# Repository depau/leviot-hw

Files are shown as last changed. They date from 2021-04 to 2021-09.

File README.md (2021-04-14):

# LevIoT - Air Purifier replacement controller

This is a replacement PCB based on ESP32 for the Levoit "True HEPA Air Purifier" Core 300, (Amazon model number: 817915027059).

It has currently not been tested yet, I just ordered it from a PCB manufacturer.

I spent around 30€ for 5 PCBs with most components pre-soldered by the PCB manufacturer, + around 13€ on AliExpress for the
push buttons, shift registers and PH connectors.

Touchpad springs and LEDs are going to be recovered from the original PCB.

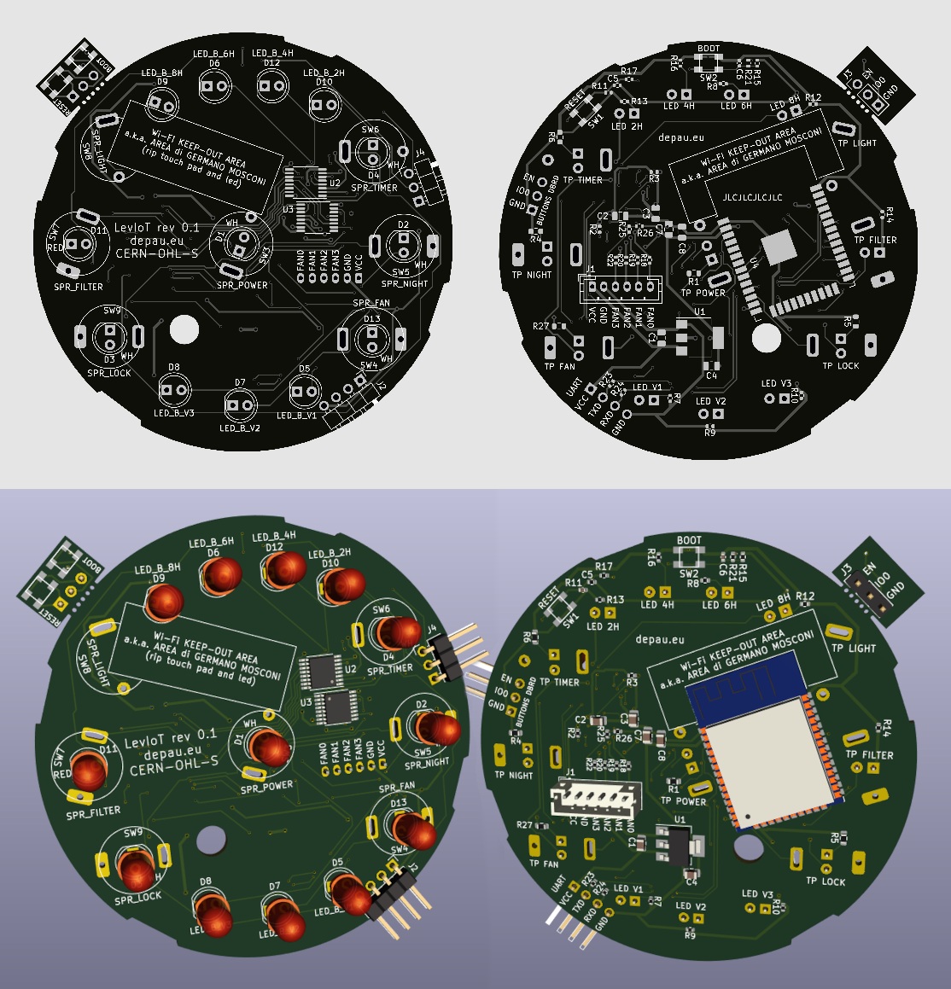
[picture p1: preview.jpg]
preview


## Taking the original board out

The top cover comes off by inserting a spudger tool between the top white and gray plastic parts.

The PCB is attached to the top plastic lid with some clips, and connected to the motor via a 6-pin JST-PH connector.

## Control board protocol

Pinout:

| Pin # | Function |
| --- | --- |
| 1 (red) | VCC |
| 2 | GND |
| 3 | Speed 3 |
| 4 | Speed 2 |
| 5 | Speed 1 |
| 6 | Night mode |

The control board simply pulls one of the pins from 3 to 6 high with the other ones low to set the speed, with all low being "off".

The motor side seems to accept pretty much any voltage > 1V as long as the current is at least ~20 mA, though when using the original
board I measure 4V across the pin and ground - current should be around 80 mA.

You can test it by placing a 100 ohm resistor between 5V and one of the speed pins.

### Important safety notice

I'm not an electrical motor expert but I know that fans need to be started at the maximum speed from the off state in order to
prevent motor strain, overheating and fire hazards.

See this video about it by Technology Connections: https://www.youtube.com/watch?v=hQ3GW7lVBWY

A custom board firmware must kickstart the fan at maximum speed for ~1 sec after power on, then set it back to whatever speed
is desired.

The original board does this automatically.

## License

CERN Open Hardware License, strictly reciprocal.

## Disclaimer

I will not take any responsibility for broken air filters caused by modding or installing this custom PCB. You take your own
responsibility.

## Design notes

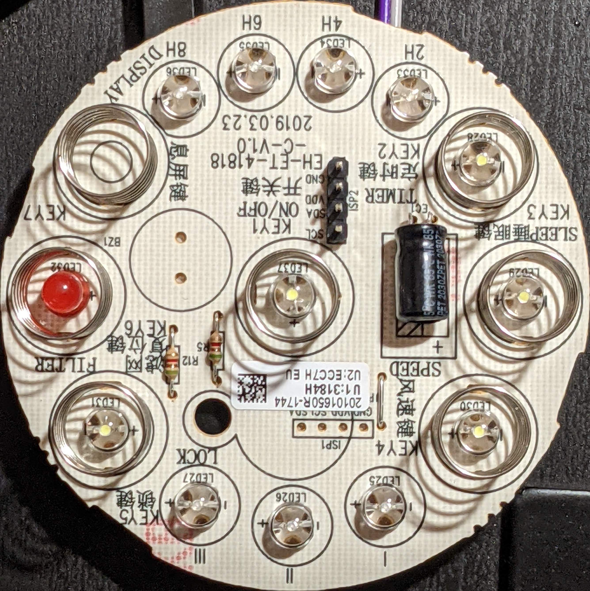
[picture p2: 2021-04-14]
front.jpg

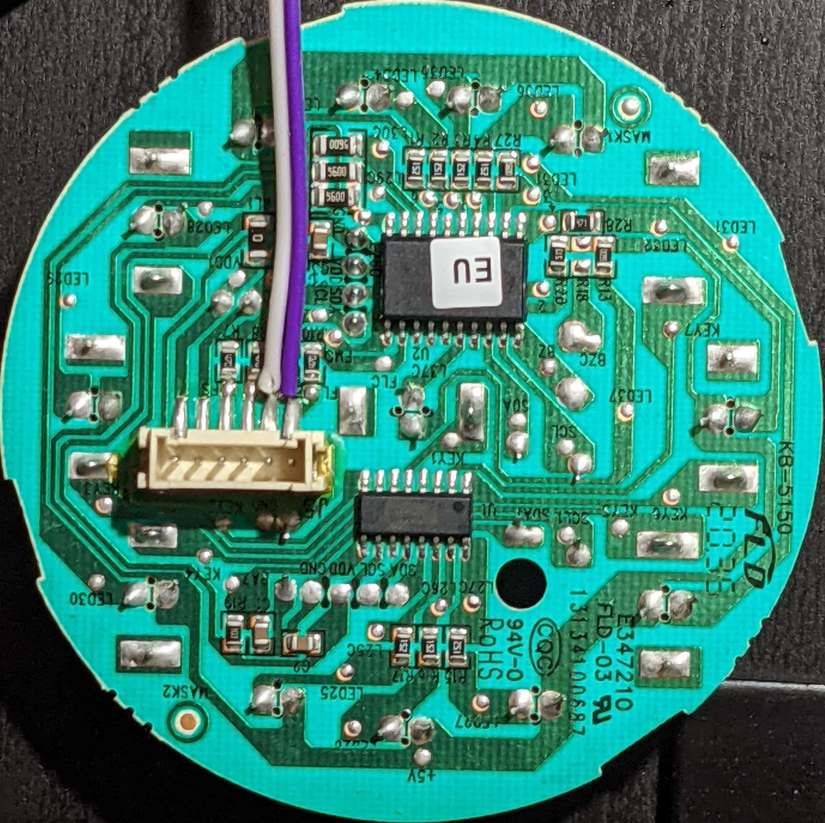
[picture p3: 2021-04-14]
back.jpg

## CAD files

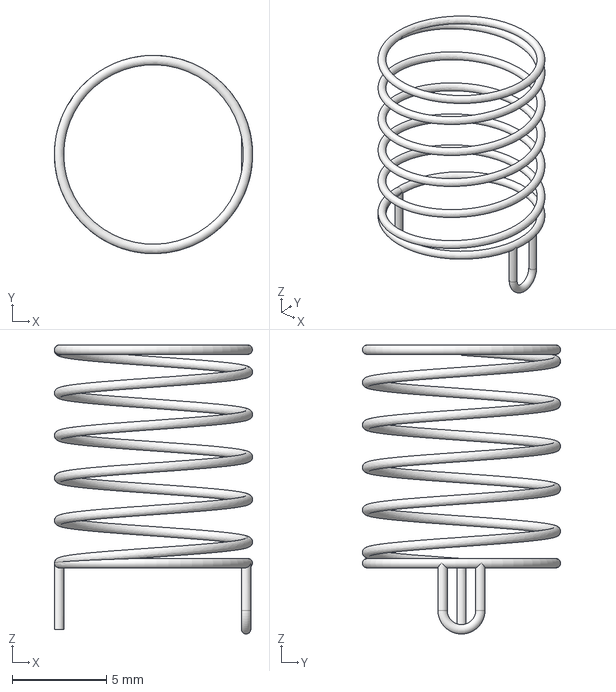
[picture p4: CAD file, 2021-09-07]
spring-3d-model/spring-3d-model.step
10.5 x 10.5 x 15.3 mm

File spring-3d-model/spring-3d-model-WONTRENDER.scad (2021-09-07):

wire_thickn = 0.5;
height = 13;
diam = 10.9;
windings = 5;
pin_len = 3.5;
slot_w = 2;

fn = 50;

/**
* An edge (or line) between 2 nodes
*/
module line(start, end, d, fn=4) {
  hull() {
    node(start,d, fn);
    node(end,d, fn);
  }      
}

/**
* A single node which is connected by edges
*/

module node(pos, d, fn=4) {
  if (pos[0]!=undef && pos[1] != undef && pos[2] != undef){ 
    translate(pos) sphere(d=d, $fn = fn);    
  }
}

module spring(d, dBottom=6, dTop=6, windings=2, height=10, steps=10, wireDiameter=1,fn=10) {
    // we use either d or dBottom&dTop
    r0 = d != undef ? d/2 : dBottom/2;
    r1 = d != undef ?d/2 : dTop/2;
    
    rx = (r0-r1) / (360.0*windings);    
    heightPerDegree = height/windings/360;
    
    for ( angle = [steps : steps : 360*windings] ){
        r = r0 - (angle * rx); 
        x0=r*cos(angle-steps);
        y0=r*sin(angle-steps);
        z0=(angle-steps)*heightPerDegree;
        x=r*cos(angle);
        y=r*sin(angle);
        z=angle*heightPerDegree;

        line([x0,y0,z0],[x,y,z],d=wireDiameter,fn=fn);        
    }
}

/**
* 3D Spring with identical diameter at top and bottom. The top and boton might
* start with a flat circle
*/
module spring3D(d=5,windings=3,height=10,flatStart=true,flatEnd=true, wireDiameter=1,  fn=4) {  
    spring(d=d, windings=windings,height=height, wireDiameter=wireDiameter, fn=fn);
    
    if (flatStart)
        spring(dBottom=d,dTop=d,windings=1,height=0, wireDiameter=wireDiameter, fn=fn);
    if (flatEnd)
        translate([0,0,height]) spring(dBottom=d,dTop=d, windings=1,height=0, wireDiameter=wireDiameter, fn=fn);
}

union() {
  spring3D(diam, windings=windings, height=height, wireDiameter=wire_thickn, fn=fn);
  
  translate([-diam/2, 0, -pin_len - wire_thickn/2])
  cylinder(d=wire_thickn, h=pin_len+(wire_thickn/2), $fn=fn);
  
  translate([diam/2 , 0, -pin_len+slot_w-wire_thickn]) {
    rotate([90, 0, 90])
    rotate_extrude(angle=180, convexity=10, $fn=fn)
    translate([-slot_w/2 + wire_thickn, 0])
    circle(d=wire_thickn, $fn=fn);
    
    translate([0, -slot_w/2 + wire_thickn])
    cylinder(d=wire_thickn, h=pin_len-slot_w/2 - wire_thickn, $fn=fn);
    
    translate([0, slot_w/2 - wire_thickn])
    cylinder(d=wire_thickn, h=pin_len-slot_w/2 - wire_thickn, $fn=fn);
  }
}

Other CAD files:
spring-3d-model/spring-3d-model1.step
spring-3d-model/spring-3d-model.f3d
spring-3d-model/spring-3d-model1.f3d

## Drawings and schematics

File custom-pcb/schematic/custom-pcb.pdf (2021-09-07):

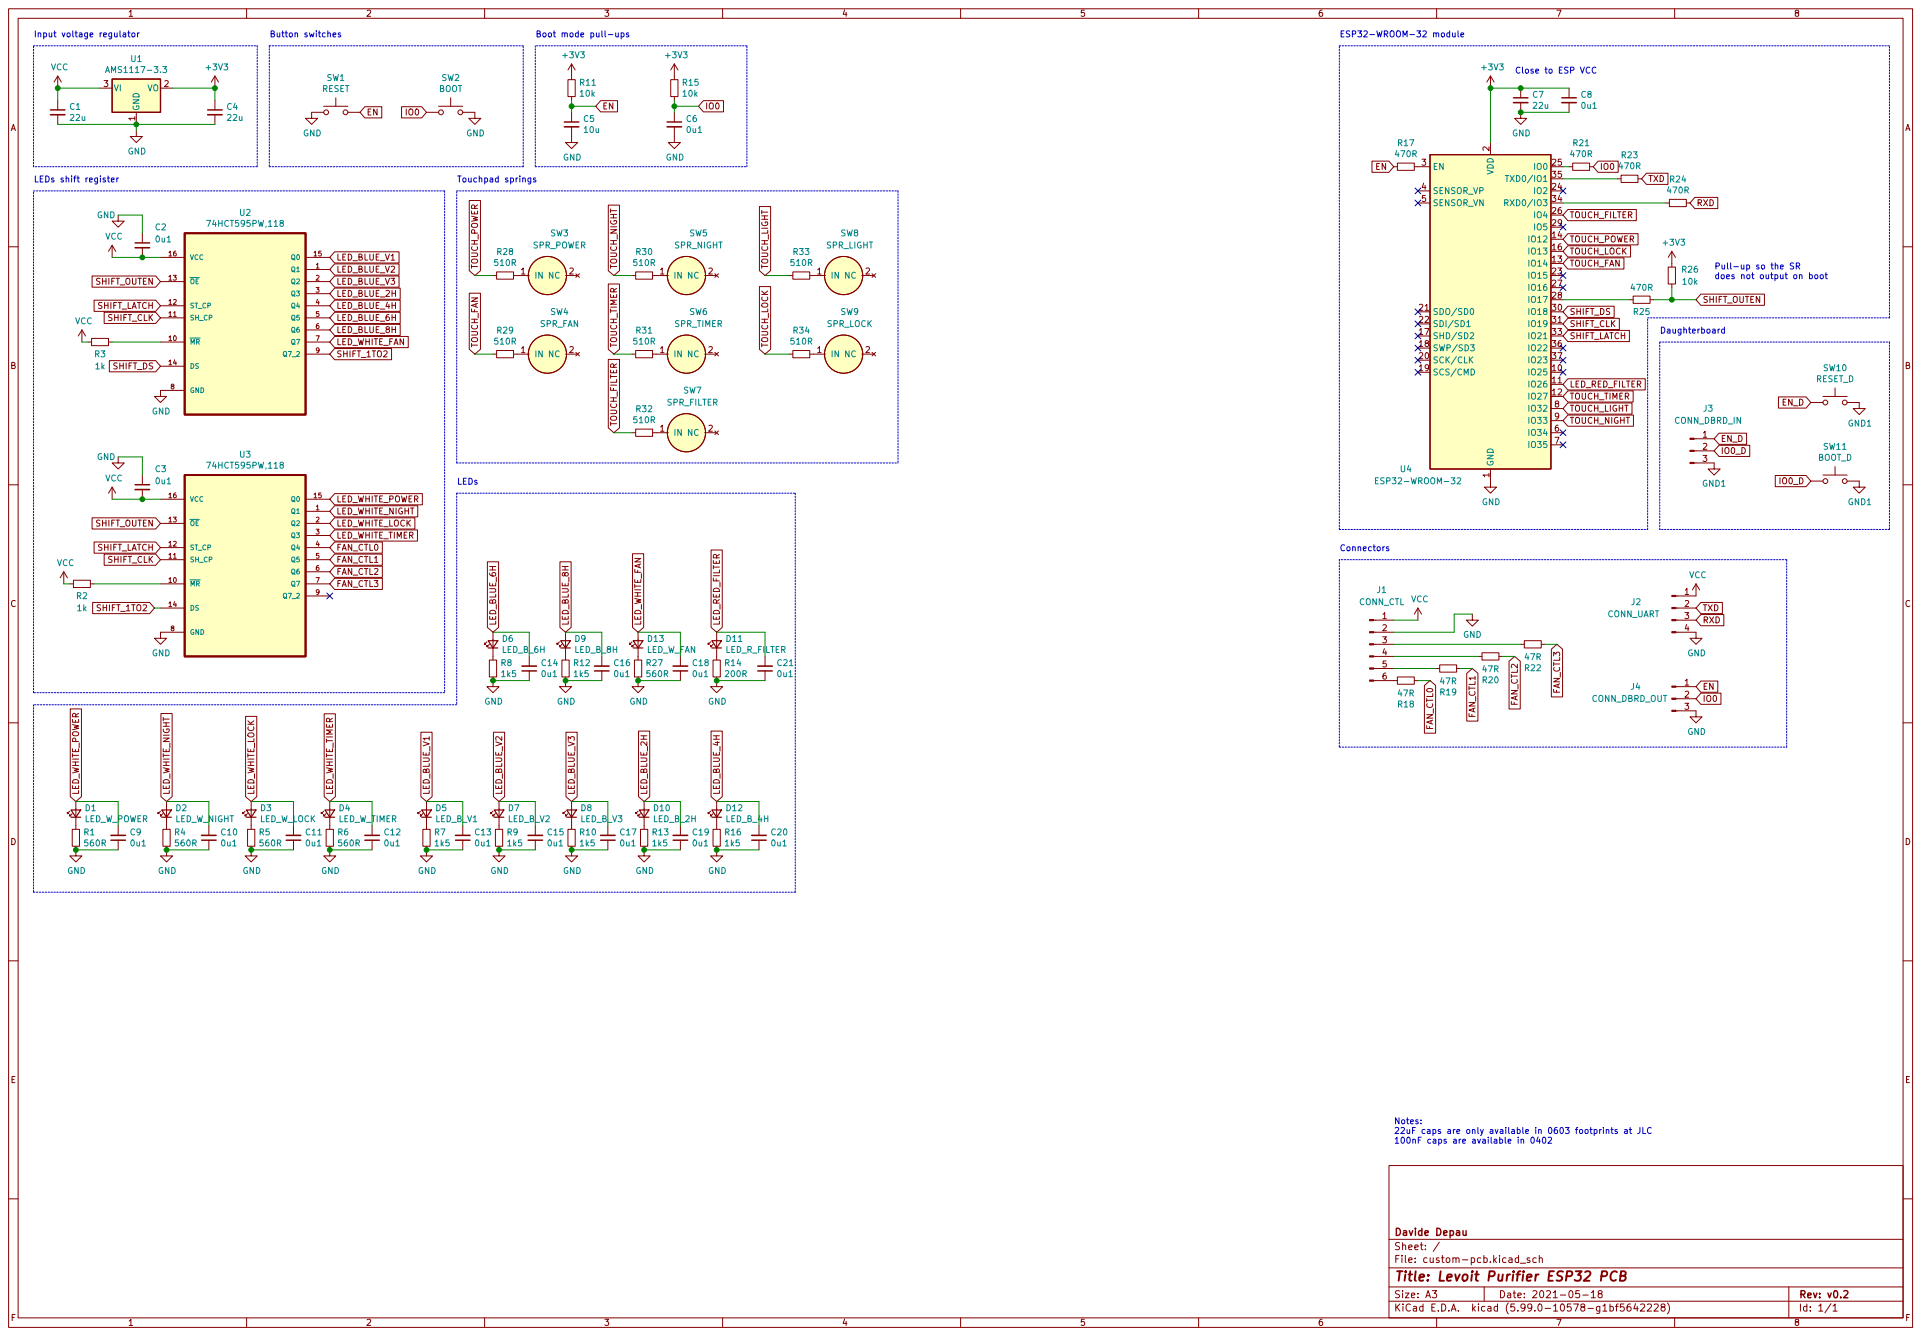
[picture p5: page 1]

Button switches LEDs shift register

2 SCK/CLK 20 SDO/SD0 21 SDI/SD1 22

Pull-up so the SR
does not output on boot

Notes: 22uF caps are only available in 0603 footprints at JLC

100nF caps are available in 0402

File: custom-pcb.kicad_sch Sheet: / Davide Depau

Id: 1/1 Title: Levoit Purifier ESP32 PCB

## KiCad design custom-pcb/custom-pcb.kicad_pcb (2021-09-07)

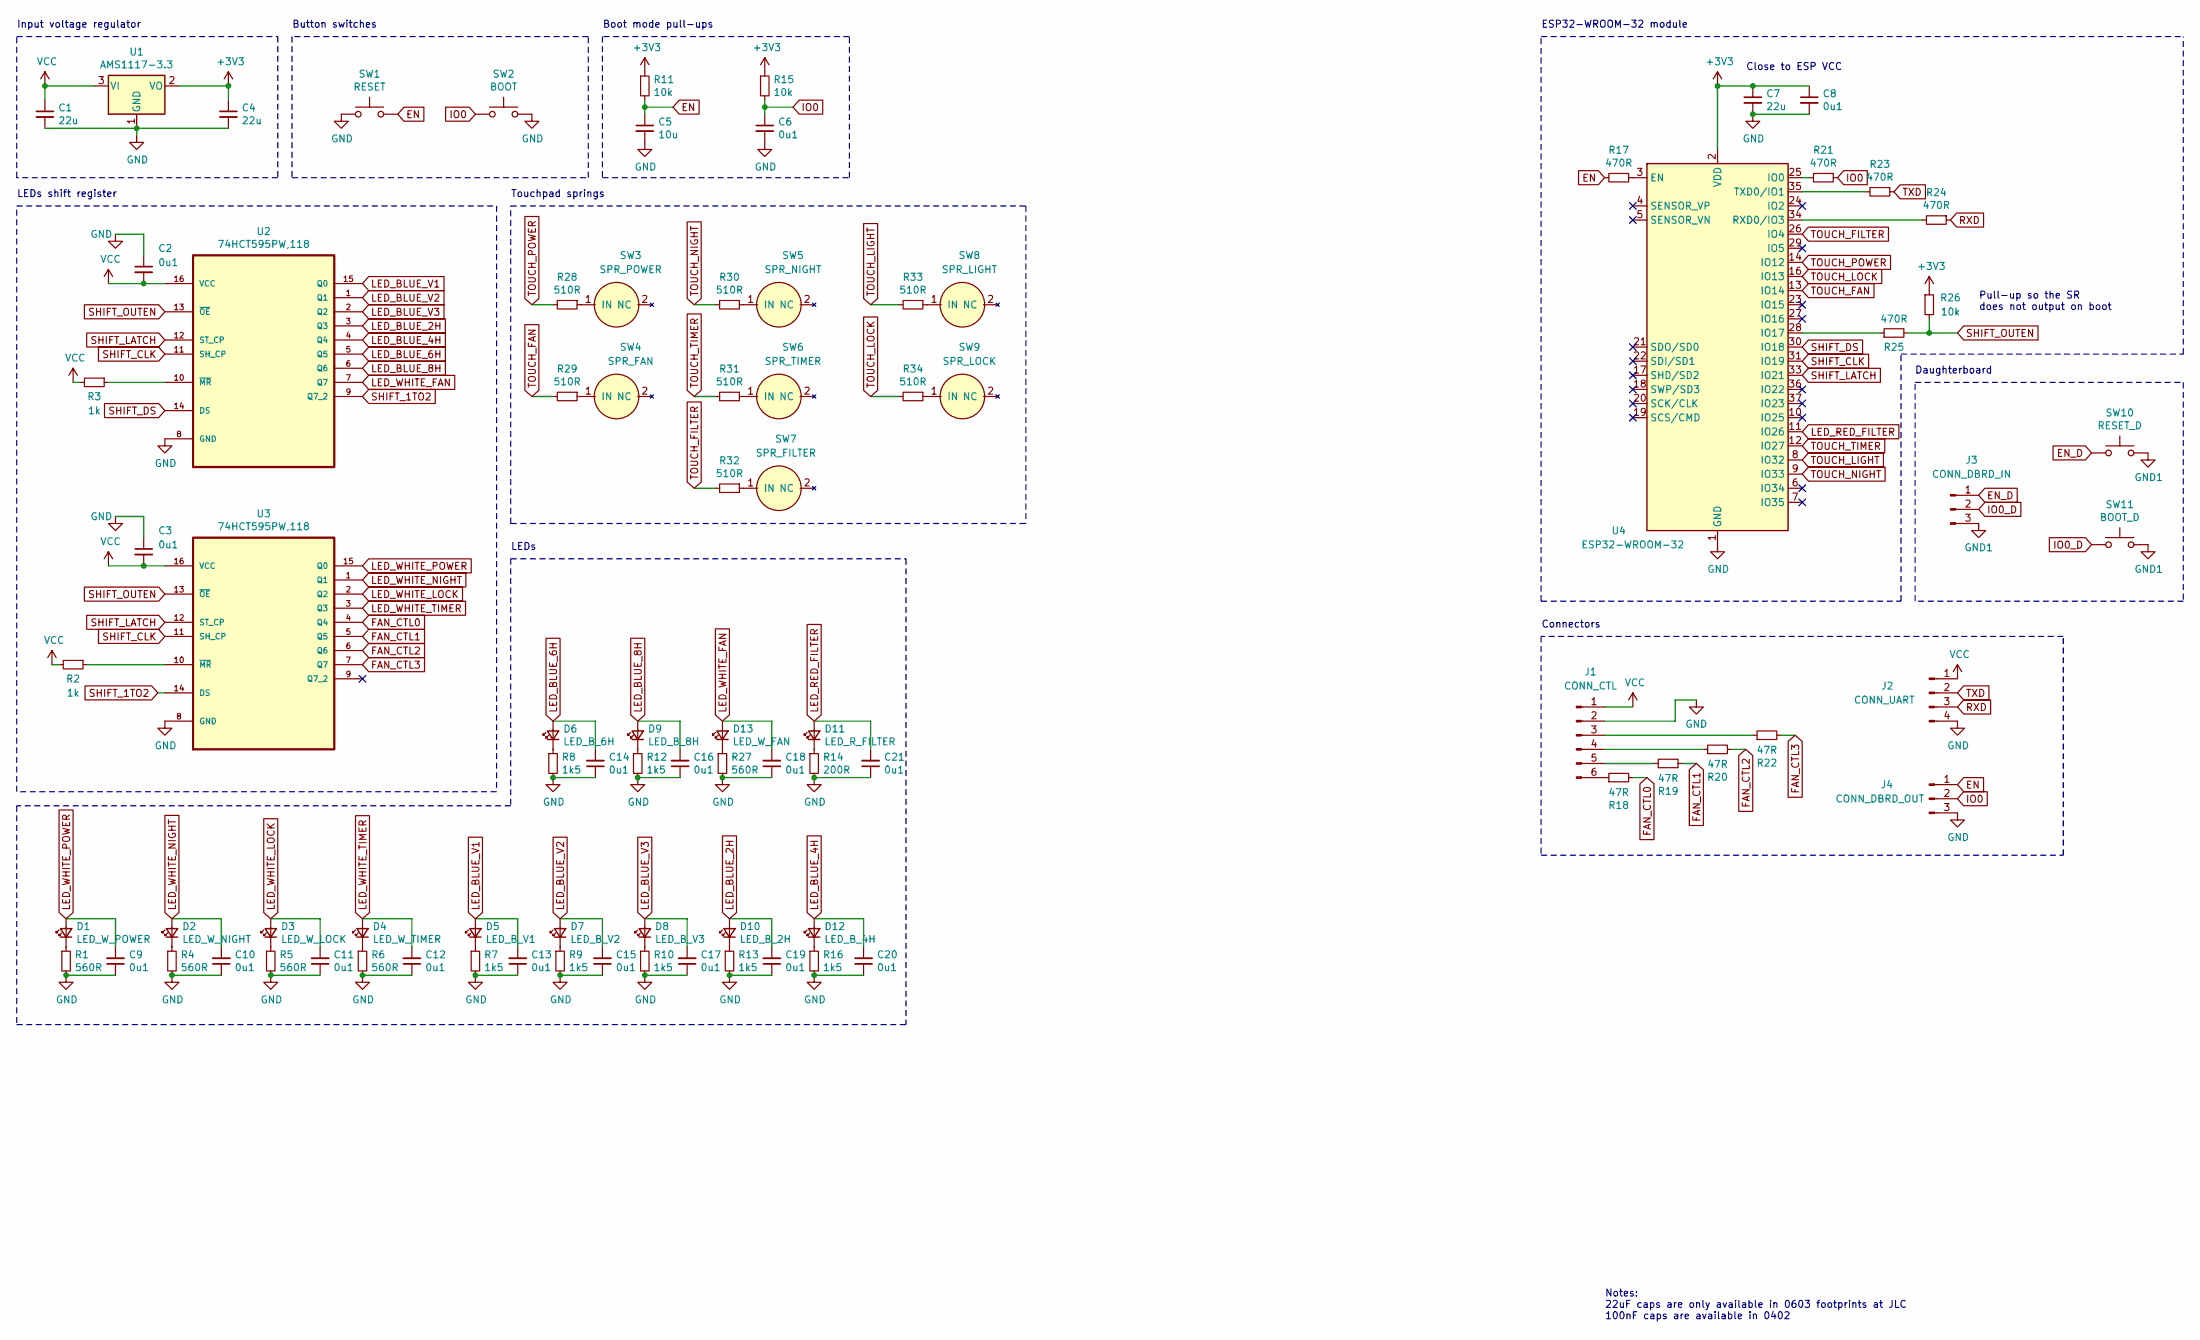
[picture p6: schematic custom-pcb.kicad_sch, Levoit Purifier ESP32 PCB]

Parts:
C1, C4, C7: 22u; C_0805_2012Metric; LCSC Part C45783
C2, C3, C8: 0u1; C_0805_2012Metric; LCSC Part C49678
C5: 10u; C_0402_1005Metric; LCSC Part C15525
C6: 0u1; C_0402_1005Metric; LCSC Part C1525
C9, C10, C11, C12, C13, C14, C15, C16, C17, C18, C19, C20, C21: 0u1; C_0402_1005Metric
D1: LED_W_POWER; LED_D5.0mm-centered; JLCPCB BOM 0
D2: LED_W_NIGHT; LED_D5.0mm-centered; JLCPCB BOM 0
D3: LED_W_LOCK; LED_D5.0mm-centered; JLCPCB BOM 0
D4: LED_W_TIMER; LED_D5.0mm-centered; JLCPCB BOM 0
D5: LED_B_V1; LED_0603_1608Metric_Pad1.05x0.95mm_HandSolder; JLCPCB BOM 0
D6: LED_B_6H; LED_0603_1608Metric_Pad1.05x0.95mm_HandSolder; JLCPCB BOM 0
D7: LED_B_V2; LED_0603_1608Metric_Pad1.05x0.95mm_HandSolder; JLCPCB BOM 0
D8: LED_B_V3; LED_0603_1608Metric_Pad1.05x0.95mm_HandSolder; JLCPCB BOM 0
D9: LED_B_8H; LED_0603_1608Metric_Pad1.05x0.95mm_HandSolder; JLCPCB BOM 0
D10: LED_B_2H; LED_0603_1608Metric_Pad1.05x0.95mm_HandSolder; JLCPCB BOM 0
D11: LED_R_FILTER; LED_D5.0mm-centered; JLCPCB BOM 0
D12: LED_B_4H; LED_0603_1608Metric_Pad1.05x0.95mm_HandSolder; JLCPCB BOM 0
D13: LED_W_FAN; LED_D5.0mm-centered; JLCPCB BOM 0
J1: CONN_CTL; JST_PH_B6B-PH-K_1x06_P2.00mm_Vertical; JLCPCB BOM 0
J2: CONN_UART; PinHeader_1x04_P2.54mm_Vertical; JLCPCB BOM 0
J3: CONN_DBRD_IN; PinHeader_1x03_P2.54mm_Vertical; JLCPCB BOM 0
J4: CONN_DBRD_OUT; PinHeader_1x03_P2.54mm_Vertical; JLCPCB BOM 0
R1, R4, R5, R6, R27: 560R; R_0603_1608Metric; LCSC Part C23204
R2, R3: 1k; R_0402_1005Metric; LCSC Part C11702
R7, R8, R9, R10, R12, R13, R16: 1k5; R_0402_1005Metric; LCSC Part C25867
R11, R15, R26: 10k; R_0402_1005Metric; LCSC Part C25744
R14: 200R; R_0402_1005Metric; LCSC Part C25087
R17, R21, R23, R24, R25: 470R; R_0402_1005Metric; LCSC Part C25117
R18, R19, R20, R22: 47R; R_0402_1005Metric; LCSC Part C25118
R28, R29, R30, R31, R32, R33, R34: 510R; R_0402_1005Metric; LCSC Part C25125
SW1: RESET; Tactile_Push_Button_SMD_3x3x1.5mm.kicad_mod; JLCPCB BOM 0
SW2: BOOT; Tactile_Push_Button_SMD_3x3x1.5mm.kicad_mod; JLCPCB BOM 0
SW3: SPR_POWER; touchpad_spring; JLCPCB BOM 0
SW4: SPR_FAN; touchpad_spring; JLCPCB BOM 0
SW5: SPR_NIGHT; touchpad_spring; JLCPCB BOM 0
SW6: SPR_TIMER; touchpad_spring; JLCPCB BOM 0
SW7: SPR_FILTER; touchpad_spring; JLCPCB BOM 0
SW8: SPR_LIGHT; touchpad_spring; JLCPCB BOM 0
SW9: SPR_LOCK; touchpad_spring; JLCPCB BOM 0
SW10: RESET_D; Tactile_Push_Button_SMD_3x3x1.5mm.kicad_mod; JLCPCB BOM 0
SW11: BOOT_D; Tactile_Push_Button_SMD_3x3x1.5mm.kicad_mod; JLCPCB BOM 0
U1: AMS1117-3.3; SOT-223-3_TabPin2; LCSC Part C6186
U2, U3: 74HCT595PW,118; TSSOP-16_4.4x5mm_P0.65mm; MPN 74HC595D,118; LCSC Part C99710
U4: ESP32-WROOM-32; LCSC Part C701343

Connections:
+3V3: C4.1, C7.1, C8.1, R11.1, R15.1, R26.1, U1.2 (VO), U4.2 (VDD)
EN: C5.1, J4.1, R11.2, R17.2, SW1.2
EN_D: J3.1, SW10.1
FAN_CTL0: R18.2, U3.4 (Q4)
FAN_CTL1: R19.2, U3.5 (Q5)
FAN_CTL2: R20.2, U3.6 (Q6)
FAN_CTL3: R22.2, U3.7 (Q7)
GND: C1.2, C2.1, C3.1, C4.2, C5.2, C6.2, C7.2, C8.2, C9.1, C10.1, C11.1, C12.1, C13.1, C14.1, C15.1, C16.1, C17.1, C18.1, C19.1, C20.1, C21.1, J1.2, J2.4, J4.3, R1.2, R4.2, R5.2, R6.2, R7.2, R8.2, R9.2, R10.2, R12.2, R13.2, R14.2, R16.2, R27.2, SW1.1, SW2.2, U1.1 (GND), U2.8 (GND), U3.8 (GND), U4.1 (GND), U4.15 (GND), U4.38 (GND), U4.39 (GND)
GND1: J3.3, SW10.2, SW11.2
IO0: C6.1, J4.2, R15.2, R21.1, SW2.1
IO0_D: J3.2, SW11.1
LED_BLUE_2H: C19.2, D10.2 (A), U2.3 (Q3)
LED_BLUE_4H: C20.2, D12.2 (A), U2.4 (Q4)
LED_BLUE_6H: C14.2, D6.2 (A), U2.5 (Q5)
LED_BLUE_8H: C16.2, D9.2 (A), U2.6 (Q6)
LED_BLUE_V1: C13.2, D5.2 (A), U2.15 (Q0)
LED_BLUE_V2: C15.2, D7.2 (A), U2.1 (Q1)
LED_BLUE_V3: C17.2, D8.2 (A), U2.2 (Q2)
LED_RED_FILTER: C21.2, D11.2 (A), U4.11 (IO26)
LED_WHITE_FAN: C18.2, D13.2 (A), U2.7 (Q7)
LED_WHITE_LOCK: C11.2, D3.2 (A), U3.2 (Q2)
LED_WHITE_NIGHT: C10.2, D2.2 (A), U3.1 (Q1)
LED_WHITE_POWER: C9.2, D1.2 (A), U3.15 (Q0)
LED_WHITE_TIMER: C12.2, D4.2 (A), U3.3 (Q3)
unnamed: D1.1 (K), R1.1
unnamed: D2.1 (K), R4.1
unnamed: D3.1 (K), R5.1
unnamed: D4.1 (K), R6.1
unnamed: D5.1 (K), R7.1
unnamed: D6.1 (K), R8.1
unnamed: D7.1 (K), R9.1
unnamed: D8.1 (K), R10.1
unnamed: D9.1 (K), R12.1
unnamed: D10.1 (K), R13.1
unnamed: D11.1 (K), R14.1
unnamed: D12.1 (K), R16.1
unnamed: D13.1 (K), R27.1
unnamed: J1.3, R22.1
unnamed: J1.4, R20.1
unnamed: J1.5, R19.1
unnamed: J1.6, R18.1
unnamed: R2.1, U3.10 (~MR)
unnamed: R3.1, U2.10 (~MR)
unnamed: R17.1, U4.3 (EN)
unnamed: R21.2, U4.25 (IO0)
unnamed: R23.2, U4.35 (TXD0/IO1)
unnamed: R24.2, U4.34 (RXD0/IO3)
unnamed: R25.1, U4.28 (IO17)
unnamed: R28.1, SW3.1 (IN)
unnamed: R29.1, SW4.1 (IN)
unnamed: R30.1, SW5.1 (IN)
unnamed: R31.1, SW6.1 (IN)
unnamed: R32.1, SW7.1 (IN)
unnamed: R33.1, SW8.1 (IN)
unnamed: R34.1, SW9.1 (IN)
RXD: J2.3, R24.1
SHIFT_1TO2: U2.9 (Q7_2), U3.14 (DS)
SHIFT_CLK: U2.11 (SH_CP), U3.11 (SH_CP), U4.31 (IO19)
SHIFT_DS: U2.14 (DS), U4.30 (IO18)
SHIFT_LATCH: U2.12 (ST_CP), U3.12 (ST_CP), U4.33 (IO21)
SHIFT_OUTEN: R25.2, R26.2, U2.13 (~OE), U3.13 (~OE)
TOUCH_FAN: R29.2, U4.13 (IO14)
TOUCH_FILTER: R32.2, U4.26 (IO4)
TOUCH_LIGHT: R33.2, U4.8 (IO32)
TOUCH_LOCK: R34.2, U4.16 (IO13)
TOUCH_NIGHT: R30.2, U4.9 (IO33)
TOUCH_POWER: R28.2, U4.14 (IO12)
TOUCH_TIMER: R31.2, U4.12 (IO27)
TXD: J2.2, R23.1
VCC: C1.1, C2.2, C3.2, J1.1, J2.1, R2.2, R3.2, U1.3 (VI), U2.16 (VCC), U3.16 (VCC)

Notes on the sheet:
Input voltage regulator
LEDs shift register
Button switches
Touchpad springs
LEDs
Boot mode pull-ups
ESP32-WROOM-32 module
Connectors
Notes: 22uF caps are only available in 0603 footprints at JLC 100nF caps are available in 0402
Close to ESP VCC
Pull-up so the SR does not output on boot
Daughterboard

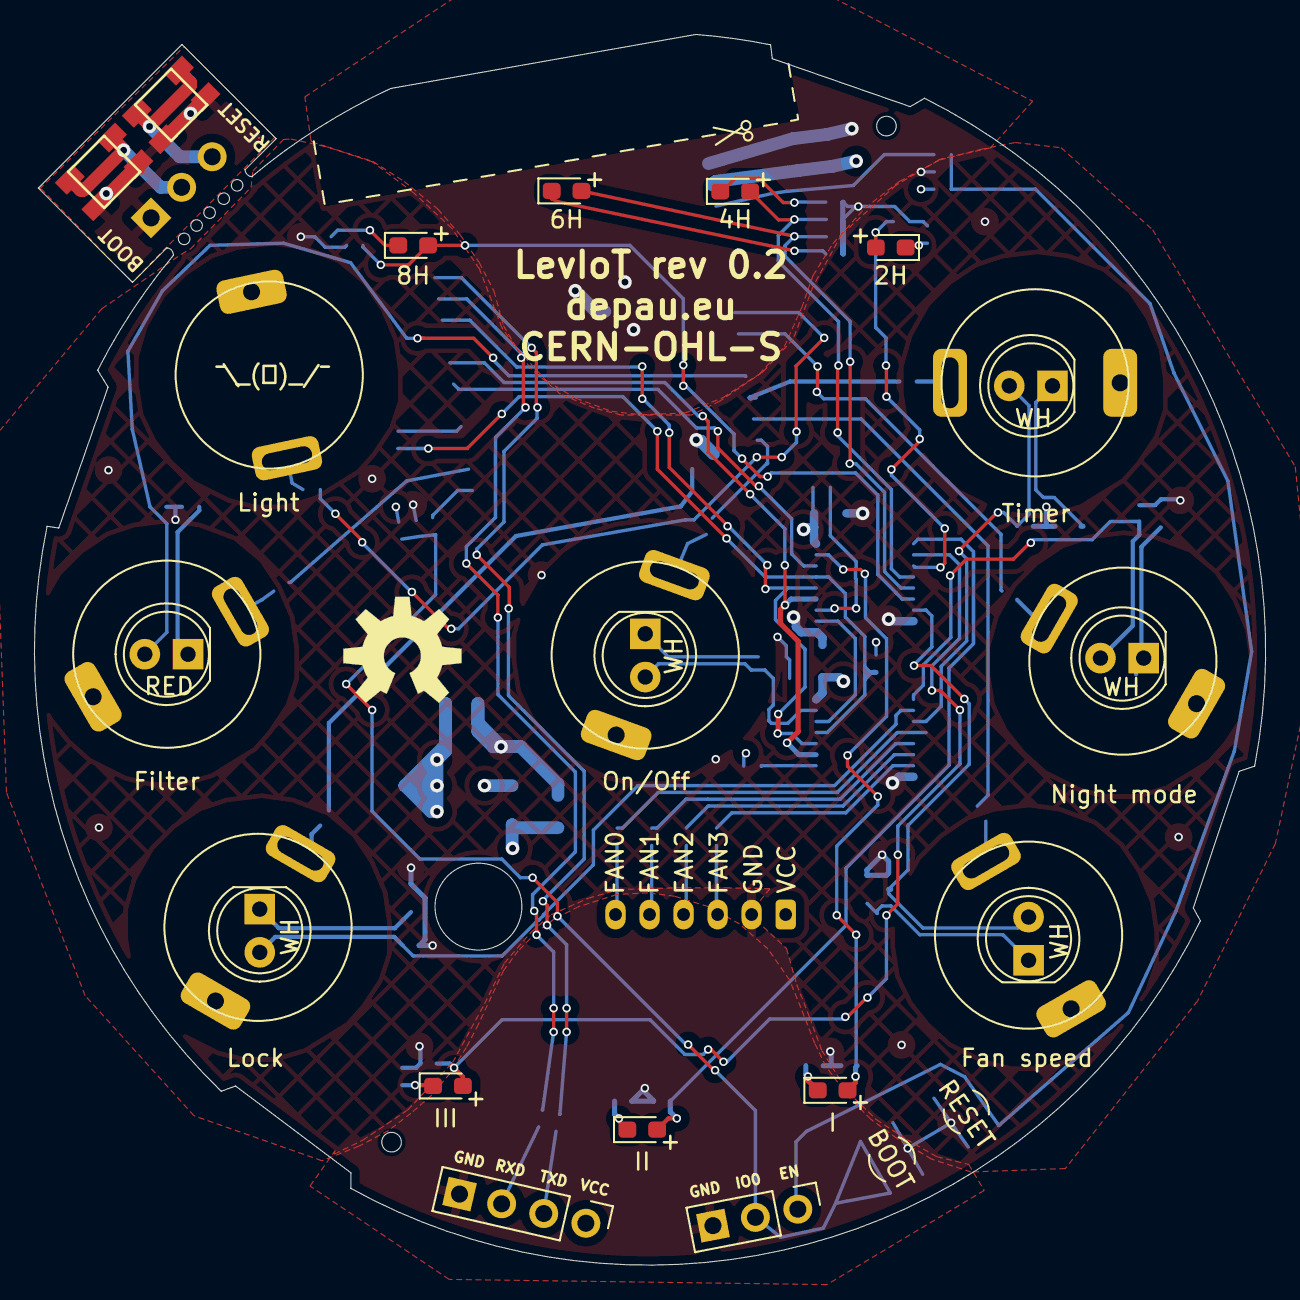
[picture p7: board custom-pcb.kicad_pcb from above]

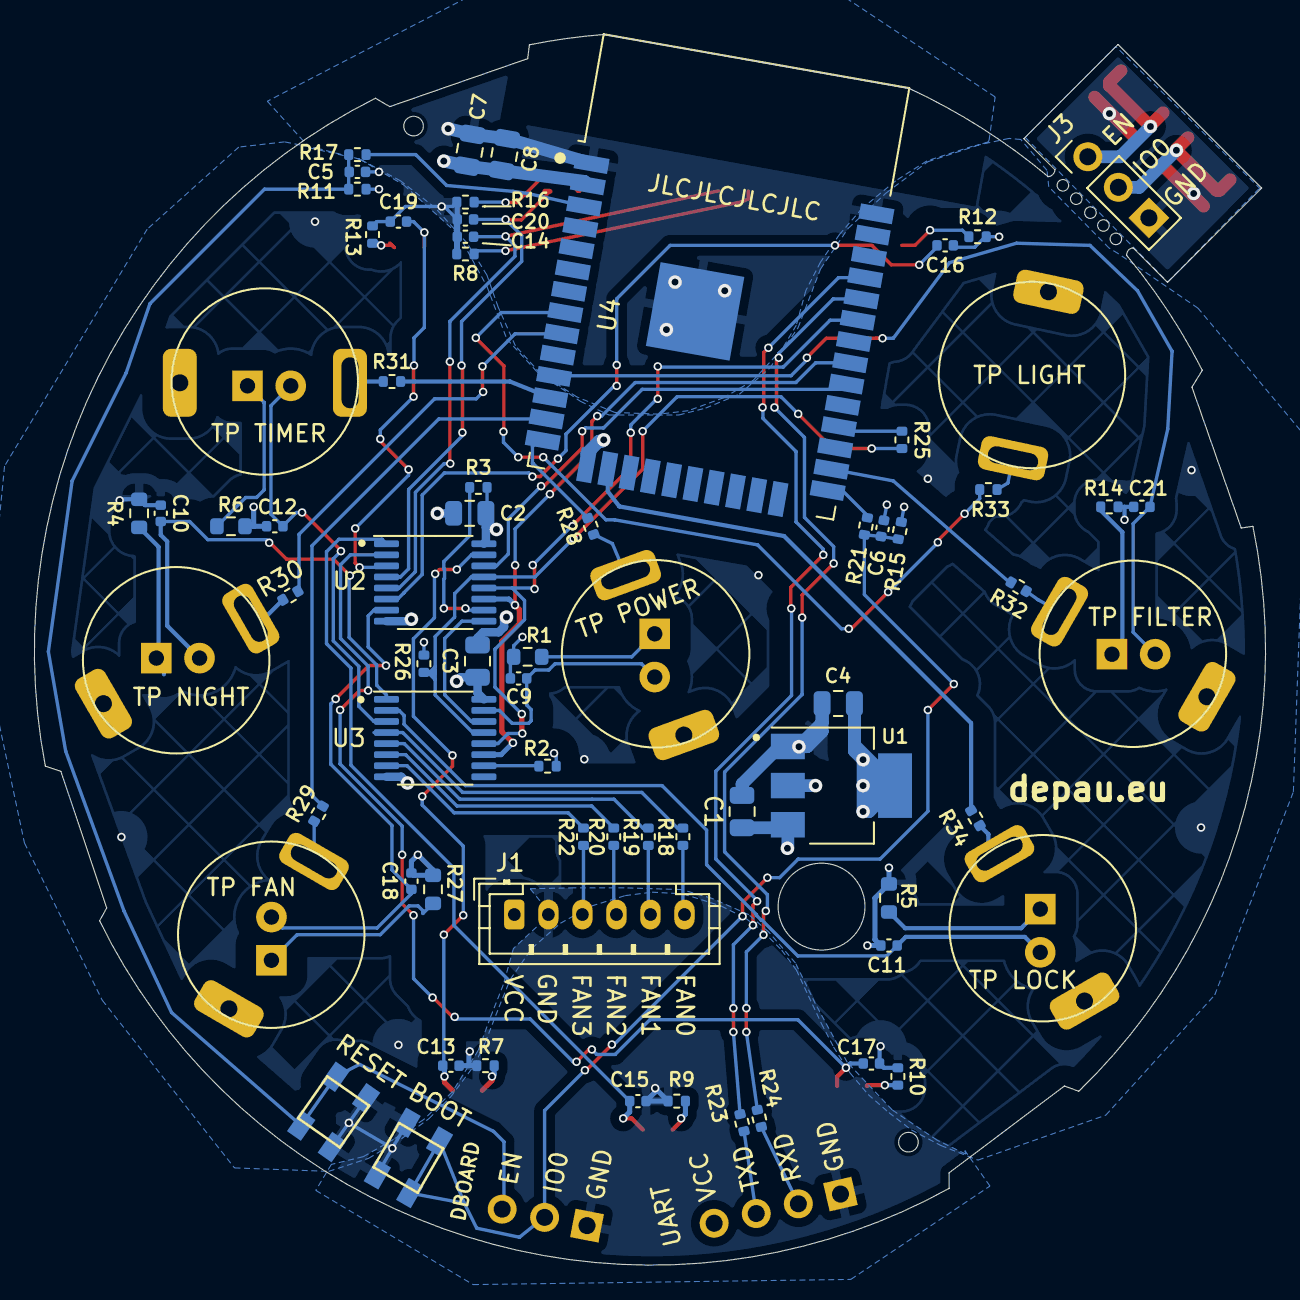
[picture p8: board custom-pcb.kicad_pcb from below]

Board: 4 copper layers, 72.4 x 72.3 mm, 88 parts (63 on the bottom side), 70 nets.

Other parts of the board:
board_alignments: LEVOIT_CTL_BOARD_ALIGN; board-alignments

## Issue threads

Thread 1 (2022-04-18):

Original Board Question

lavachemist, 2022-04-18:
Hello,

I haven't pulled the Levoit 300 apart yet, but I'm curious what the original board uses. Do you have pictures of it, by any chance?

I have a couple of Levoit smart humidifiers ("Classic 200S" ASIN: B08KXW1KRJ), which have ESP32-Solo-1C chips on them. I was hoping the 300 would already be ESP based. Is it not?

-LC

Depau, 2022-04-18:
Here you go (closing since it's not an issue, feel free to continue using the thread for questions)

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

Depau, 2022-04-18:
Ah you may be interested in these two too:

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

Closed 2022-04-18.

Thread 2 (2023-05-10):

Re: Any updates on your board

letshin, 2023-05-10:
Hi, I wanted to ask if you managed to test the PCB you made and how it has been functioning. Did you manage to get a new revision out of the PCB?

depau, 2023-05-10:
Hi! Actually yes! I forgot/haven't felt like updating the readme appropriately, and i haven't tagged the new version, but the latest commits should produce the new board. You can check on kicad.

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

This new PCB uses surface-mount LEDs to save space and allow placing the esp32 on the side, which helps reduce noise.

Unfortunately it still has some slight issues, mostly due to the fact that I'm not an expert at PCB design and touchpads are highly sensitive to noise.

This board, once the touchpad is properly calibrated, has been doing its job for both me and @thypon for almost 1½ years.

There are two issues:

- The touchpad occasionally becomes unresponsive (but remote control works fine). I haven't figured this out yet, mostly since unplugging it solves the issue
- The filter change indicator LED is not particularly reliable (but I remember to change the filter and ignore the indicator, so I've had no incentive to look into it)

Overall it works and I could mail you my PCBs (the one in the picture) if you're willing to fetch and solder the missing components, or you can order it presoldered from one of the Chinese websites.

That being said, since they released the Wi-Fi model right after I finished up my boards, I'd recommend getting that instead since it's cheaper than getting my board manufactured. My board is more fun though :)

depau, 2023-05-10:
Some more pics of the PCB I actually have on my purifier

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

letshin, 2024-04-07:
Thanks for this. Can't believe its almost been a year but I didn't realise you had responded. Been looking at air filters again as we have a little one coming and have more or less settled on an Ikea one as the HA forums has some PCB designs for them that someone has put together.

Closed 2024-04-07.

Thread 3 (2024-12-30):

Possible to use ESP32 devkit directly

sarabveer, 2024-12-30:
I have the Levoit Core 300 (didn't know the Core 300s existed at the time, I had already purchased the Core 300).

I have a ESP32 devkit, is it possible to control the fan directly? I do not mind losing touch controls. The issue I can think of is the ESP32 outputs 3.3v and the motor pins are at ~4v.

depau, 2024-12-30:
Hi, It's been a long time since I worked on this but if I remember correctly the pins need 5V which your ESP won't provide unless you use a logic level shifter or other circuit. You can give it a shot though.

depau, 2024-12-30:
I don't know what's the maximum current draw for ESP32 GPIO pins but if it works you should be good!

If you don't use my firmware remember to always start the motor at full speed when powering it up, then lower it back down if needed.

sarabveer, 2024-12-30:
Max current per GPIO pin seems to be 40mA, with total sum max being 120mA. Should be OK I think.

Closed 2024-12-30.

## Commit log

2021-05-09 Connect unconnected pads
    [custom-pcb.kicad_pcb]
2021-05-18 Increase EN capacitor value
    [custom-pcb.sch]
2021-05-18 Add LED filter caps and touchpad series res
    [custom-pcb.sch]
2021-05-18 Change blue LED footprints to SMD
    [custom-pcb.sch]
2021-09-07 Latest changes
    [custom-pcb-B_Cu.gbr, custom-pcb-B_Mask.gbr, custom-pcb-B_Paste.gbr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]

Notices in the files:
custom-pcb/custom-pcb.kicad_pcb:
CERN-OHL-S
